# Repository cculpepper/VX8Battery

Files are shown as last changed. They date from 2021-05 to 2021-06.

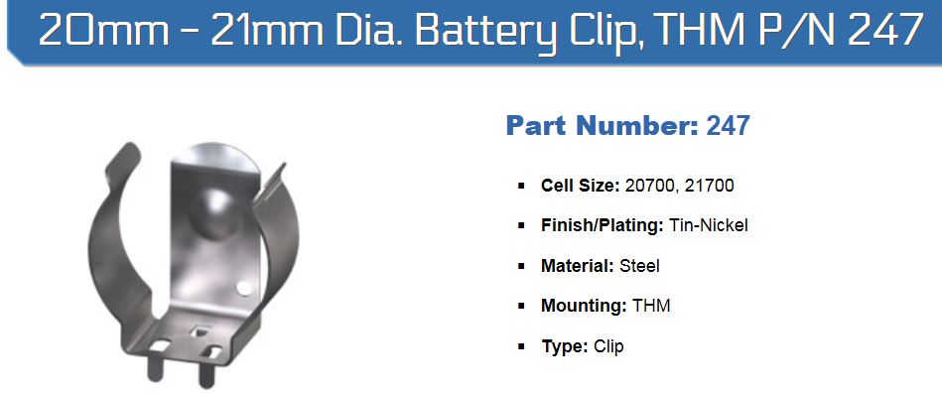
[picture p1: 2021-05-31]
backPlate/keystone-electronics-21700-20700-single-cell-clip-pth-1.snapshot.1/Keystone-PN247 specification.JPG

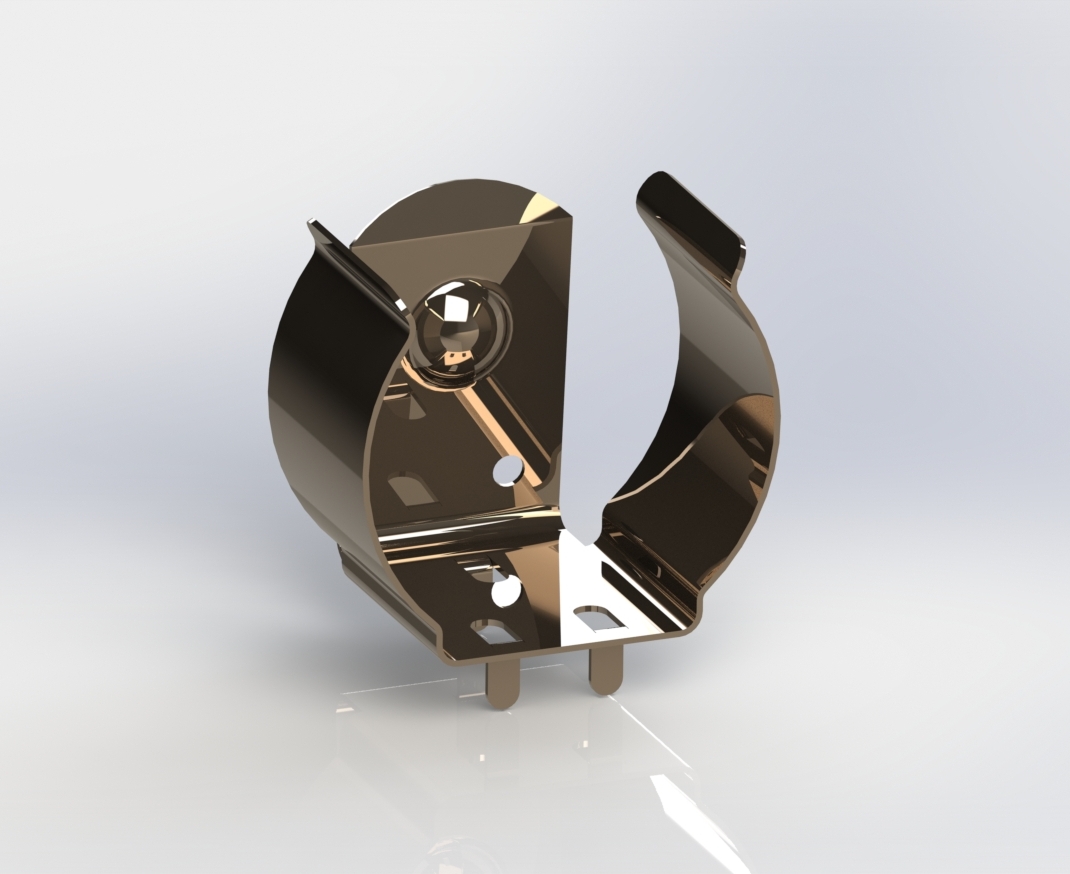
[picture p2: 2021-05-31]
backPlate/keystone-electronics-21700-20700-single-cell-clip-pth-1.snapshot.1/keystone-PN247 iso rendering.JPG

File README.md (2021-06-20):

This is a printed and PCB'ed battery for the VX8DR. 

I've been using it for approx 2 days now, and it seems to work great. 

I printed the case, backPlate/VX8PrintedCase-WithLightPipes.stl in PLA, 0.15mm. The 0.15 or smaller seems to be important for the clips, so you have more walls. It features two heat-serts for M3 screws for the beltclip. You may want to trim with a file the clips and the passive end clips, but I did not need to. The light pipes were made of 1.75mm clear PETG, and I had to drill them out to 2mm in post. The USB-C hole fits all of my cables, and is probably a bit too big so you'll have to fish around in there to plug it in. 

I had the PCB made up in 0.8mm from JLCPCB, seems to work great, but does bend a bit. The SMT nuts are from adafruit, https://www.adafruit.com/product/4207 . These work great. The interactive bom is in the circuit folder, and should have relevant manufacturer PNs from Digikey, except for the jellybean parts. The chip will charge at 1.2A from the 5V line, and will /eventually/ balance unbalanced cells. There is NO PROTECTION between the cells and the radio interface, so you should use protected cells...

After soldering, you'll need to grind or file the battery clips, SMT nuts, and thermistor to not protrude. IT IS IMPORTANT TO INSULATE THE BACK OF THE PCB. I used 2 layers of kapton. Don't screw this up! 
Also you'll need to trim the "bottom" of the attached PCB, you'll see that it doesn't fit into the 3d printed case. When I up the PCB version, I'll fix that. 

For assembly, I found the easiest thing (after testing the cells fit) is to put the cells into the case in the right orientation, then put the PCB with the battery clips in, "catching" the batteries. Then you can put in the M3 screws into the SMT nuts.

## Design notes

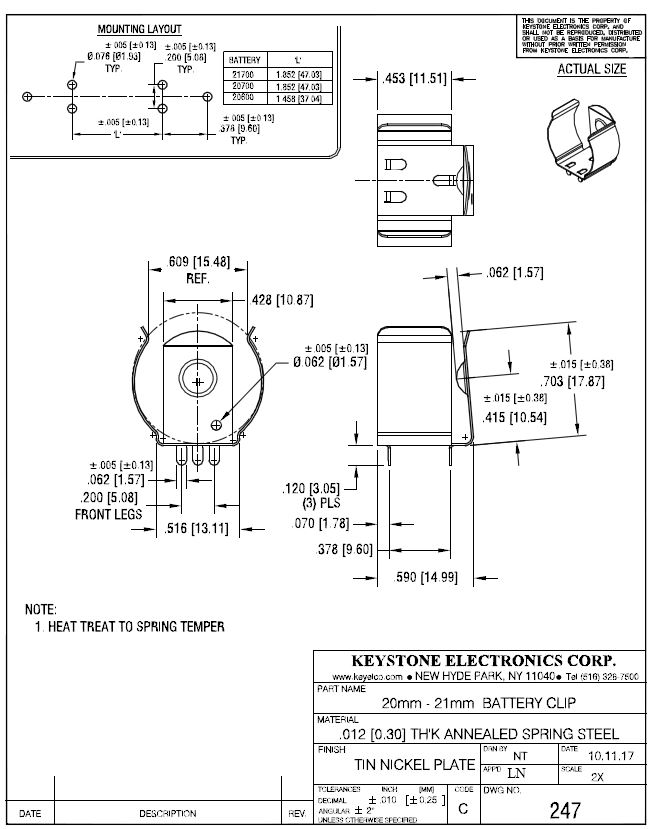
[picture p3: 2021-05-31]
backPlate/keystone-electronics-21700-20700-single-cell-clip-pth-1.snapshot.1/Keystone-PN247 mechanical.JPG

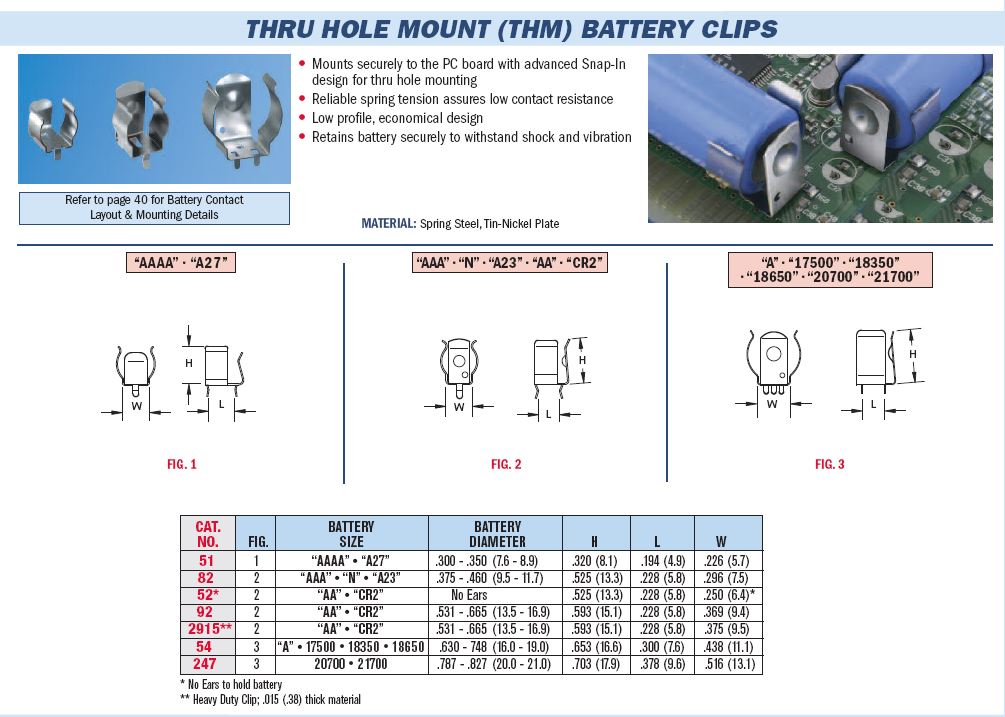
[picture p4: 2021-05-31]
backPlate/keystone-electronics-21700-20700-single-cell-clip-pth-1.snapshot.1/Keystone-PN247 catalog.JPG

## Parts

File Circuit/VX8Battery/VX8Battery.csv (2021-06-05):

Source: | /home/chris/Code/VX8Battery/Circuit/VX8Battery/VX8Battery.kicad_sch
Date: | Fri 04 Jun 2021 10:37:11 PM EDT
Tool: | Eeschema (5.99.0-10712-g3100cd3599)
Generator: | /usr/share/kicad/plugins/bom_csv_grouped_by_value.py
Component Count: | 28
Individual Components:
Item | Qty | Reference(s) | Value | LibPart | Footprint | Datasheet | Manufacturer PN
 |  | BT1 | Battery_Cell | Device:Battery_Cell | VX8Battery:21700Battery | ~
 |  | BT2 | Battery_Cell | Device:Battery_Cell | VX8Battery:21700Battery | ~
 |  | C1 | 10uF | Device:C | Capacitor_SMD:C_1210_3225Metric | ~
 |  | C2 | 100n | Device:C | Capacitor_SMD:C_0603_1608Metric | ~
 |  | C3 | 4.7uF | Device:C | Capacitor_SMD:C_1206_3216Metric | ~
 |  | C4 | 1uF | Device:C | Capacitor_SMD:C_0805_2012Metric | ~
 |  | C5 | 22u | Device:C | Capacitor_SMD:C_1210_3225Metric | ~ | GRM21BR61E226ME44K
 |  | D1 | LED | Device:LED | LED_SMD:LED_0603_1608Metric | ~
 |  | D2 | LED | Device:LED | LED_SMD:LED_0603_1608Metric | ~
 |  | H1 | MountingHole_Pad | Mechanical:MountingHole_Pad | VX8Battery:AdafruitSMTStandoff | ~
 |  | H2 | MountingHole_Pad | Mechanical:MountingHole_Pad | VX8Battery:AdafruitSMTStandoff | ~
 |  | H3 | MountingHole_Pad | Mechanical:MountingHole_Pad | VX8Battery:AdafruitSMTStandoff | ~
 |  | J1 | USBC-Molex-2171780001 | VX8Battery:USBC-Molex-2171780001 | VX8Battery:Molex-2171780001
 |  | J2 | VX8BattPins | Connector:Conn_01x03_Female | VX8Battery:VX8BatteryPins | ~
 |  | L1 | 1.5uH | Device:L | Inductor_SMD:L_Taiyo-Yuden_NR-50xx_HandSoldering | ~ | TYS50402R2N-10
 |  | R1 | R | Device:R | Resistor_SMD:R_0603_1608Metric | ~
 |  | R2 | R | Device:R | Resistor_SMD:R_0603_1608Metric | ~
 |  | R3 | 28.7K | Device:R | Resistor_SMD:R_0603_1608Metric | ~
 |  | R4 | 10K | Device:R | Resistor_SMD:R_0603_1608Metric | ~
 |  | R5 | R | Device:R | Resistor_SMD:R_0603_1608Metric | ~
 |  | R6 | R | Device:R | Resistor_SMD:R_0603_1608Metric | ~
 |  | R7 | 20K | Device:R | Resistor_SMD:R_0603_1608Metric | ~
 |  | R8 | 17K | Device:R | Resistor_SMD:R_0603_1608Metric | ~
 |  | R9 | 100 | Device:R | Resistor_SMD:R_0603_1608Metric | ~
 |  | R10 | 12.62K | Device:R | Resistor_SMD:R_0603_1608Metric | ~
 |  | R11 | 3.63K | Device:R | Resistor_SMD:R_0603_1608Metric | ~
 |  | TH1 | Thermistor_NTC | Device:Thermistor_NTC | Resistor_THT:R_Axial_DIN0204_L3.6mm_D1.6mm_P2.54mm_Vertical | ~ | NTCLE101E3C90173
 |  | U1 | MP2672A | VX8Battery:MP2672A | VX8Battery:MP2672A
Collated Components:
Item | Qty | Reference(s) | Value | LibPart | Footprint | Datasheet | Manufacturer PN
1 | 2 | BT1, BT2 | Battery_Cell | Device:Battery_Cell | VX8Battery:21700Battery | ~
2 | 1 | C1 | 10uF | Device:C | Capacitor_SMD:C_1210_3225Metric | ~
3 | 1 | C2 | 100n | Device:C | Capacitor_SMD:C_0603_1608Metric | ~
4 | 1 | C3 | 4.7uF | Device:C | Capacitor_SMD:C_1206_3216Metric | ~
5 | 1 | C4 | 1uF | Device:C | Capacitor_SMD:C_0805_2012Metric | ~
6 | 1 | C5 | 22u | Device:C | Capacitor_SMD:C_1210_3225Metric | ~ | GRM21BR61E226ME44K
7 | 2 | D1, D2 | LED | Device:LED | LED_SMD:LED_0603_1608Metric | ~
8 | 3 | H1, H2, H3 | MountingHole_Pad | Mechanical:MountingHole_Pad | VX8Battery:AdafruitSMTStandoff | ~
9 | 1 | J1 | USBC-Molex-2171780001 | VX8Battery:USBC-Molex-2171780001 | VX8Battery:Molex-2171780001
10 | 1 | J2 | VX8BattPins | Connector:Conn_01x03_Female | VX8Battery:VX8BatteryPins | ~
11 | 1 | L1 | 1.5uH | Device:L | Inductor_SMD:L_Taiyo-Yuden_NR-50xx_HandSoldering | ~ | TYS50402R2N-10
12 | 4 | R1, R2, R5, R6 | R | Device:R | Resistor_SMD:R_0603_1608Metric | ~
13 | 1 | R3 | 28.7K | Device:R | Resistor_SMD:R_0603_1608Metric | ~
14 | 1 | R4 | 10K | Device:R | Resistor_SMD:R_0603_1608Metric | ~
15 | 1 | R7 | 20K | Device:R | Resistor_SMD:R_0603_1608Metric | ~
16 | 1 | R8 | 17K | Device:R | Resistor_SMD:R_0603_1608Metric | ~
17 | 1 | R9 | 100 | Device:R | Resistor_SMD:R_0603_1608Metric | ~
18 | 1 | R10 | 12.62K | Device:R | Resistor_SMD:R_0603_1608Metric | ~
19 | 1 | R11 | 3.63K | Device:R | Resistor_SMD:R_0603_1608Metric | ~
20 | 1 | TH1 | Thermistor_NTC | Device:Thermistor_NTC | Resistor_THT:R_Axial_DIN0204_L3.6mm_D1.6mm_P2.54mm_Vertical | ~ | NTCLE101E3C90173
21 | 1 | U1 | MP2672A | VX8Battery:MP2672A | VX8Battery:MP2672A

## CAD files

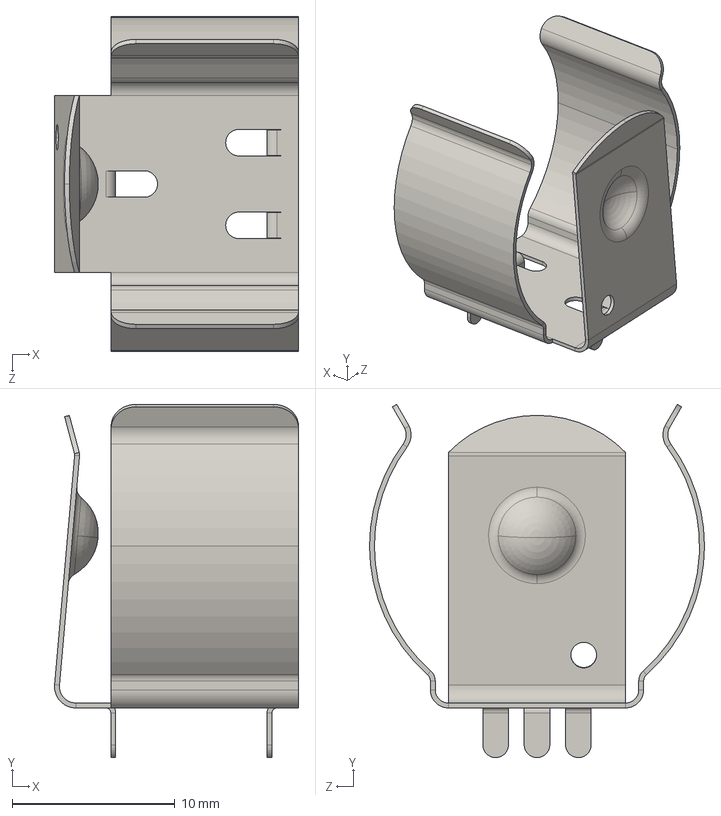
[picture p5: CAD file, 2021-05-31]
backPlate/keystone-electronics-21700-20700-single-cell-clip-pth-1.snapshot.1/keystone-PN247.STEP
15.0 x 21.7 x 20.6 mm

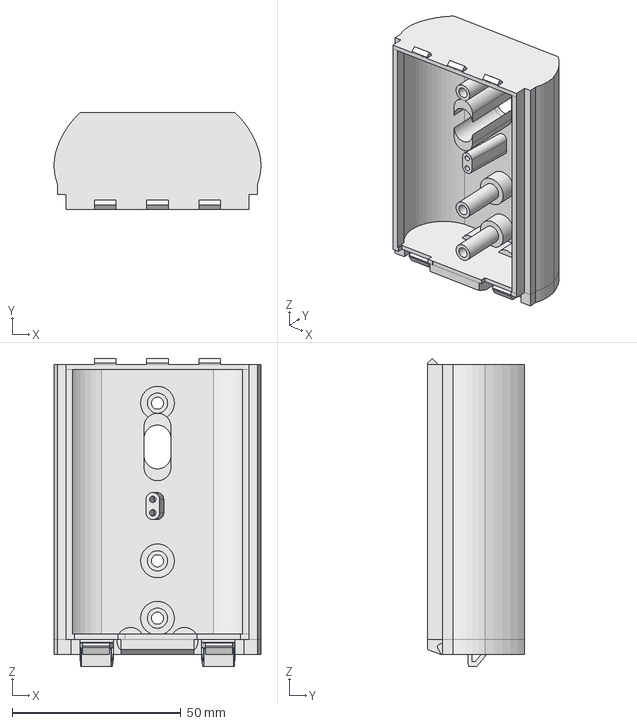
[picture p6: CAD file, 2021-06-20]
backPlate/VX8PrintedCase.FCStd
61.4 x 28.8 x 91.3 mm

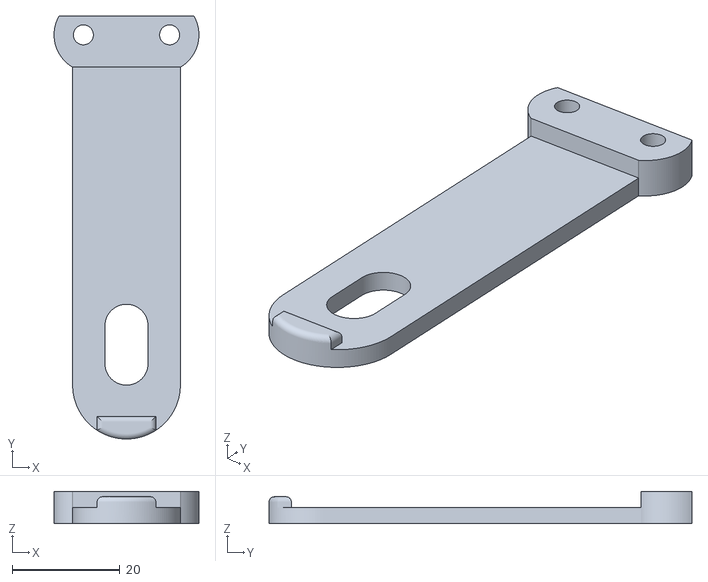
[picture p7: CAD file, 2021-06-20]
backPlate/VX8PrintedCaseBeltClip-BeltClipFillet.stl
26.9 x 78.5 x 6.00

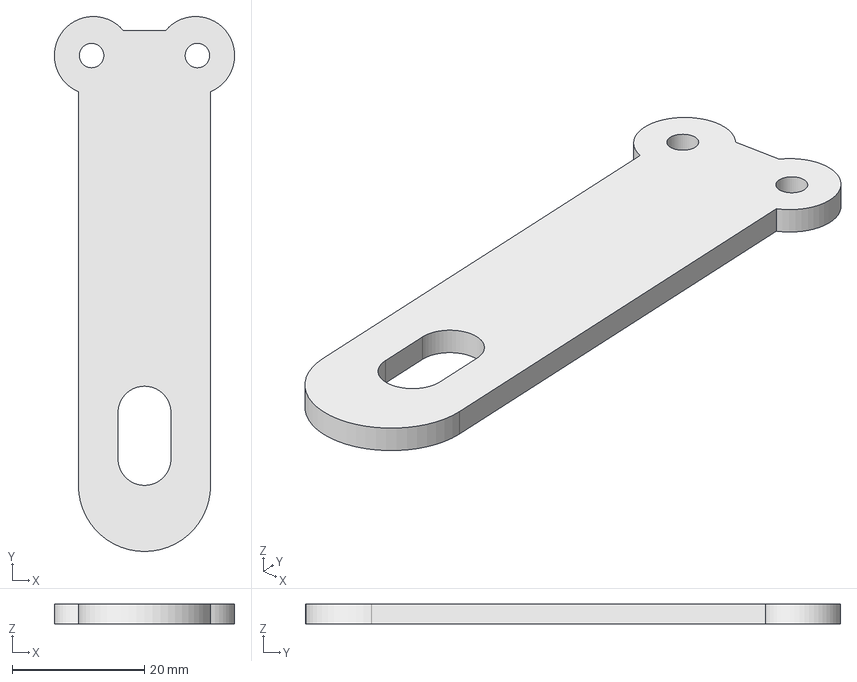
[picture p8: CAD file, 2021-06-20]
backPlate/VX8PrintedCaseBeltClip.FCStd
27.3 x 80.9 x 3.00 mm

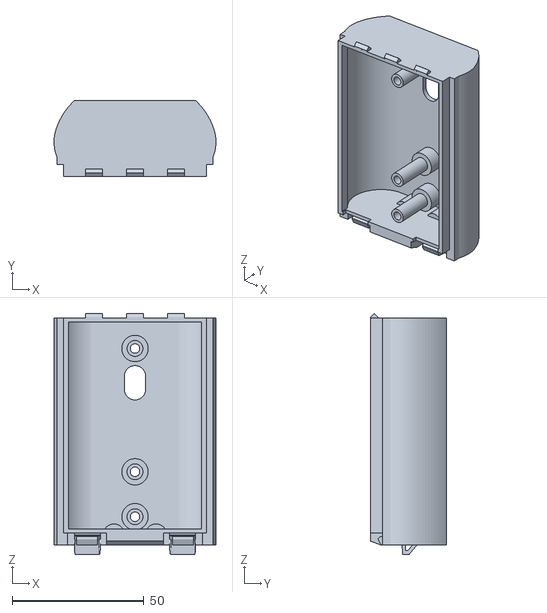
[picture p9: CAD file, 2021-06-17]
backPlate/VX8PrintedCase-WithOUTLightPipes.stl
61.4 x 28.8 x 91.3

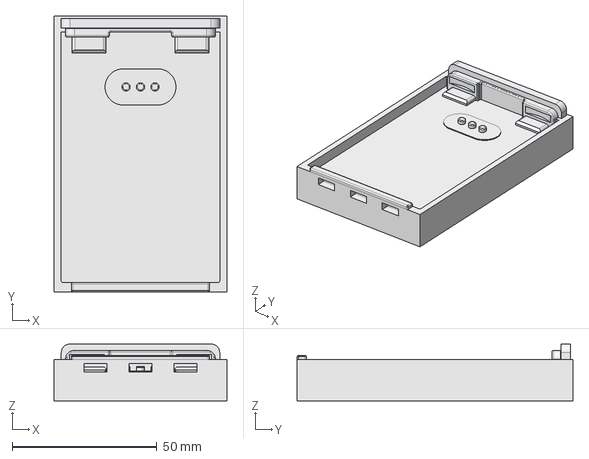
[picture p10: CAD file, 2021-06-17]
backPlate/VX8Model.FCStd
59.8 x 95.2 x 19.7 mm

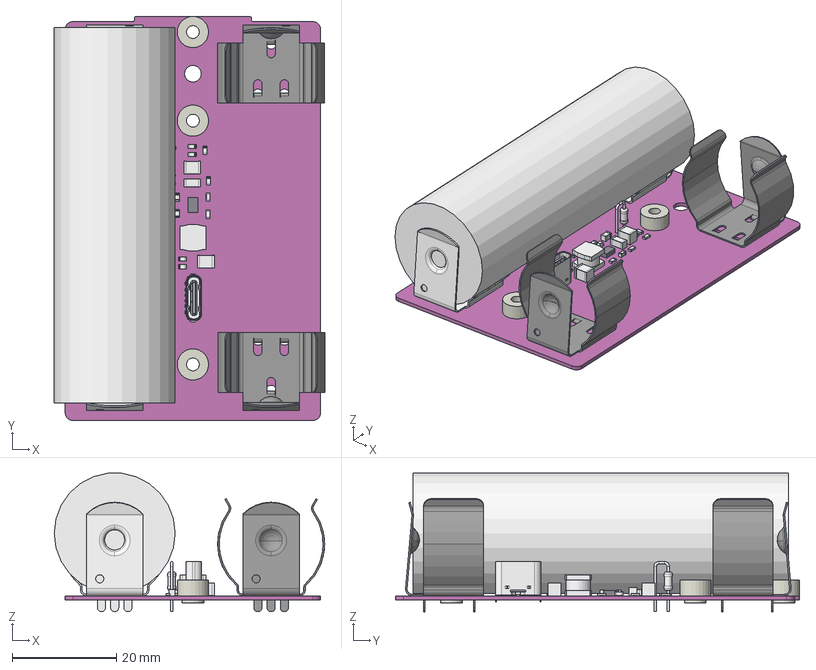
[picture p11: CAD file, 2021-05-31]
backPlate/VX8BatteryPCB.FCStd
51.9 x 77.5 x 26.6 mm
TH1_R_Axial_DIN0204_L36mm_D16mm_P254mm_Vertical_99c942fc799d
R1_R_0603_1608Metric_e04d69ce8836 x 11
U1_MP2672A_023df3fe17b2
H1_Mounting_Wuerth_WA_SMSI_M3_H3mm_9774030360_f84d812b874e x 3
J1_MolexVerticalSMDUSBC_3ee5f35280ab
C5_C_1210_3225Metric_d43db624757c x 2
C2_C_0603_1608Metric_7b14ea18a6a0
C4_C_0805_2012Metric_7cbe0b741b72
21700BatteryHolder-WithBattery
21700BatteryHolder-WithBattery001
21700BatteryHolder-WithBattery002
D2_LED_0603_1608Metric_f960d8dfa779 x 2
21700BatteryHolder-NoBattery
21700BatteryHolder-NoBattery001
inductor
inductor001
inductor002
C3_C_1206_3216Metric_fab75bc0fda4
Pcb_a240

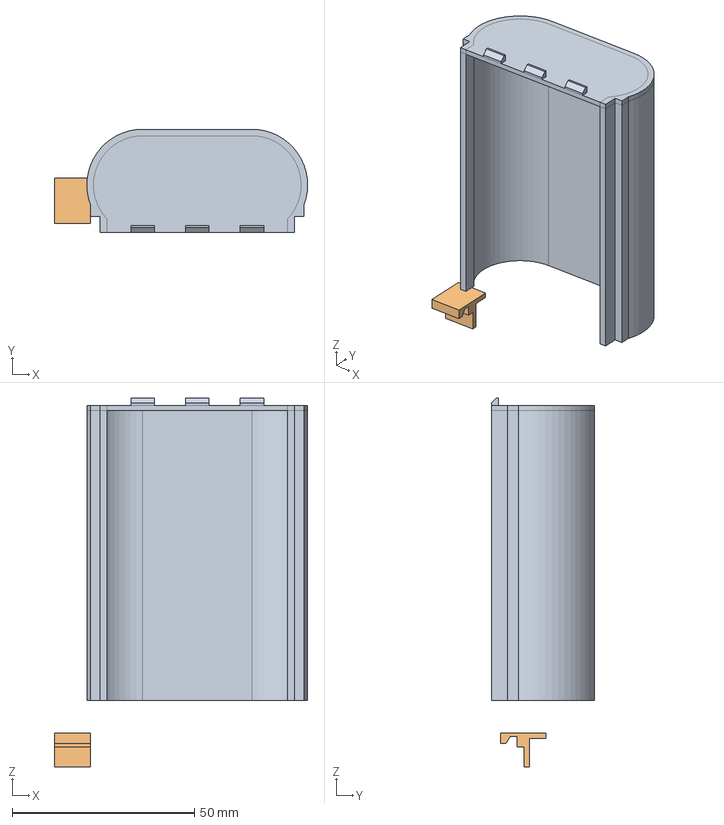
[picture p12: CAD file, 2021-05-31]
backPlate/BatteryClip.FCStd
69.6 x 28.4 x 101.3 mm
BaseFeature

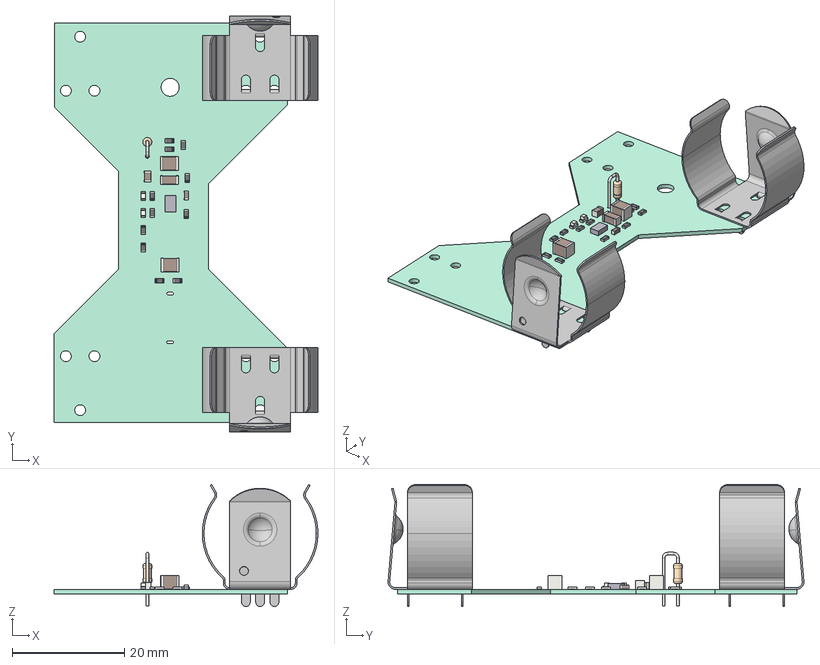
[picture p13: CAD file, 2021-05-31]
backPlate/VX8BatteryPCB-VX8Battery.step
46.9 x 74.0 x 21.7 mm
Pcb_a240
TH1_R_Axial_DIN0204_L36mm_D16mm_P254mm_Vertical_99c942fc799d
R1_R_0603_1608Metric_e04d69ce8836 x 11
U1_MP2672A_023df3fe17b2
C5_C_1210_3225Metric_d43db624757c x 2
C2_C_0603_1608Metric_7b14ea18a6a0
C4_C_0805_2012Metric_7cbe0b741b72
D2_LED_0603_1608Metric_f960d8dfa779 x 2
21700BatteryModel-NoBattery
21700BatteryModel-NoBattery001
C3_C_1206_3216Metric_fab75bc0fda4

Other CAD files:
backPlate/VX8BatteryAssembly.FCStd
backPlate/VX8PrintedCase-WithLightPipes.stl

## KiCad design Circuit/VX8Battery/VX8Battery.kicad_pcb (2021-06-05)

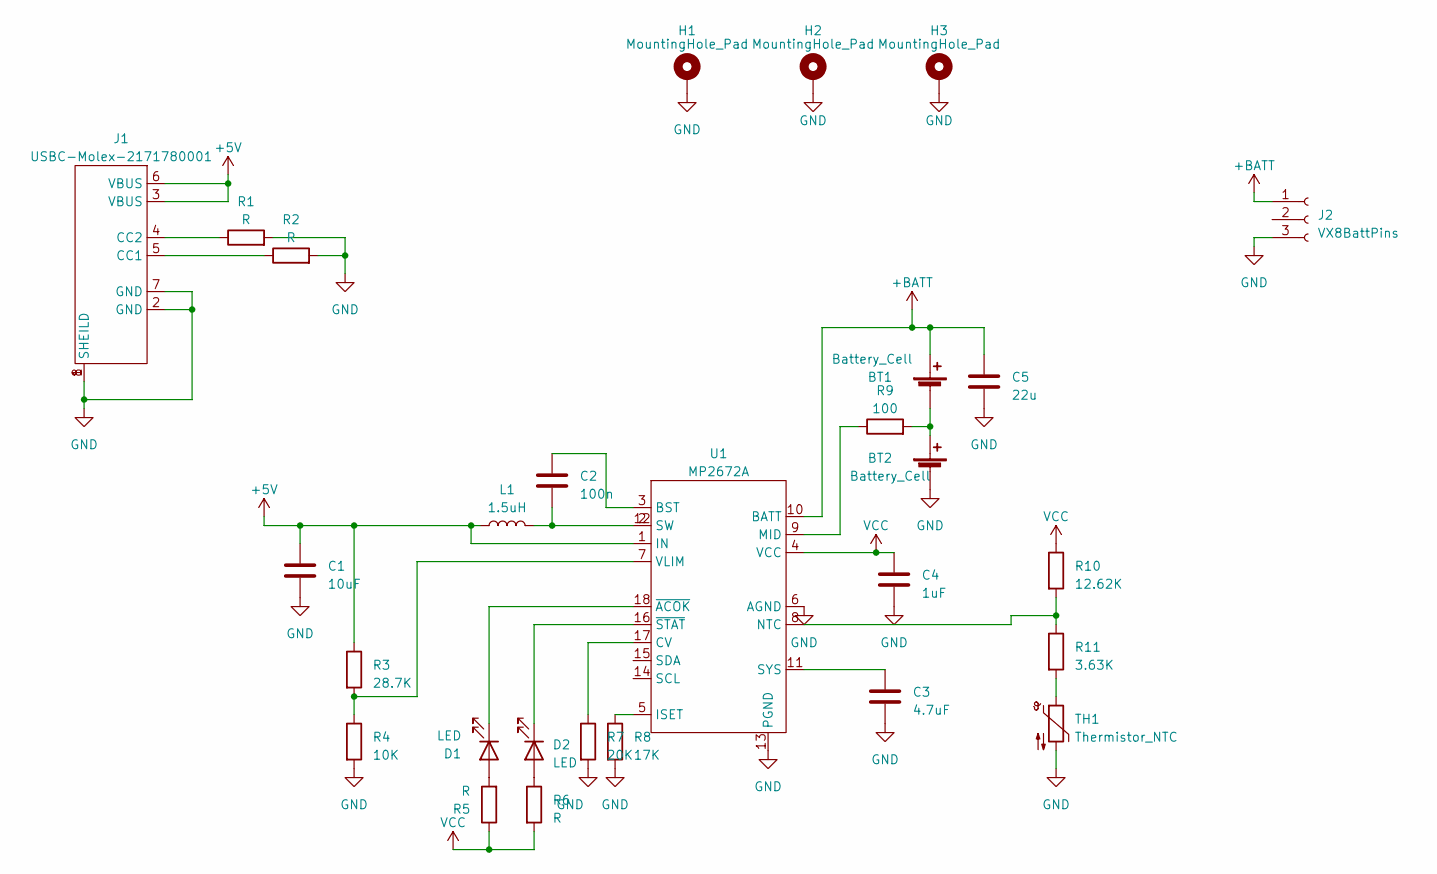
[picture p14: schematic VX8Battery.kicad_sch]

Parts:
BT1, BT2: Battery_Cell; 21700Battery
C1: 10uF; C_1210_3225Metric
C2: 100n; C_0603_1608Metric
C3: 4.7uF; C_1206_3216Metric
C4: 1uF; C_0805_2012Metric
C5: 22u; C_1210_3225Metric; Manufacturer PN GRM21BR61E226ME44K
D1, D2: LED; LED_0603_1608Metric
H1, H2, H3: MountingHole_Pad; AdafruitSMTStandoff
J1: USBC-Molex-2171780001; Molex-2171780001
J2: VX8BattPins; VX8BatteryPins
L1: 1.5uH; L_Taiyo-Yuden_NR-50xx_HandSoldering; Manufacturer PN TYS50402R2N-10
R1, R2, R5, R6: R; R_0603_1608Metric
R3: 28.7K; R_0603_1608Metric
R4: 10K; R_0603_1608Metric
R7: 20K; R_0603_1608Metric
R8: 17K; R_0603_1608Metric
R9: 100; R_0603_1608Metric
R10: 12.62K; R_0603_1608Metric
R11: 3.63K; R_0603_1608Metric
TH1: Thermistor_NTC; R_Axial_DIN0204_L3.6mm_D1.6mm_P2.54mm_Vertical; Manufacturer PN NTCLE101E3C90173
U1: MP2672A

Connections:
+5V: C1.1, J1.3 (VBUS), J1.6 (VBUS), L1.1, R3.1, U1.1 (IN)
+BATT: BT1.1 (+), C5.1, J2.1, U1.10 (BATT)
GND: BT2.2 (-), C1.2, C3.2, C4.2, C5.2, H1.1, H2.1, H3.1, J1.1 (SHEILD), J1.2 (GND), J1.7 (GND), J1.8 (SHEILD), J2.3, R1.2, R2.2, R4.2, R7.2, R8.2, TH1.2, U1.6 (AGND), U1.13 (PGND)
unnamed: BT1.2 (-), BT2.1 (+), R9.2
unnamed: C2.1, L1.2, U1.2 (SW), U1.12 (SW)
unnamed: C2.2, U1.3 (BST)
unnamed: C3.1, U1.11 (SYS)
unnamed: D1.2 (A), R5.2
unnamed: D2.2 (A), R6.1
unnamed: J1.4 (CC2), R1.1
unnamed: J1.5 (CC1), R2.1
unnamed: R3.2, R4.1, U1.7 (VLIM)
unnamed: R7.1, U1.17 (CV)
unnamed: R8.1, U1.5 (ISET)
unnamed: R9.1, U1.9 (MID)
unnamed: R10.2, R11.1, U1.8 (NTC)
unnamed: R11.2, TH1.1
unnamed: D2.1 (K), U1.16 (~STAT)
unnamed: D1.1 (K), U1.18 (~ACOK)
VCC: C4.1, R5.1, R6.2, R10.1, U1.4 (VCC)

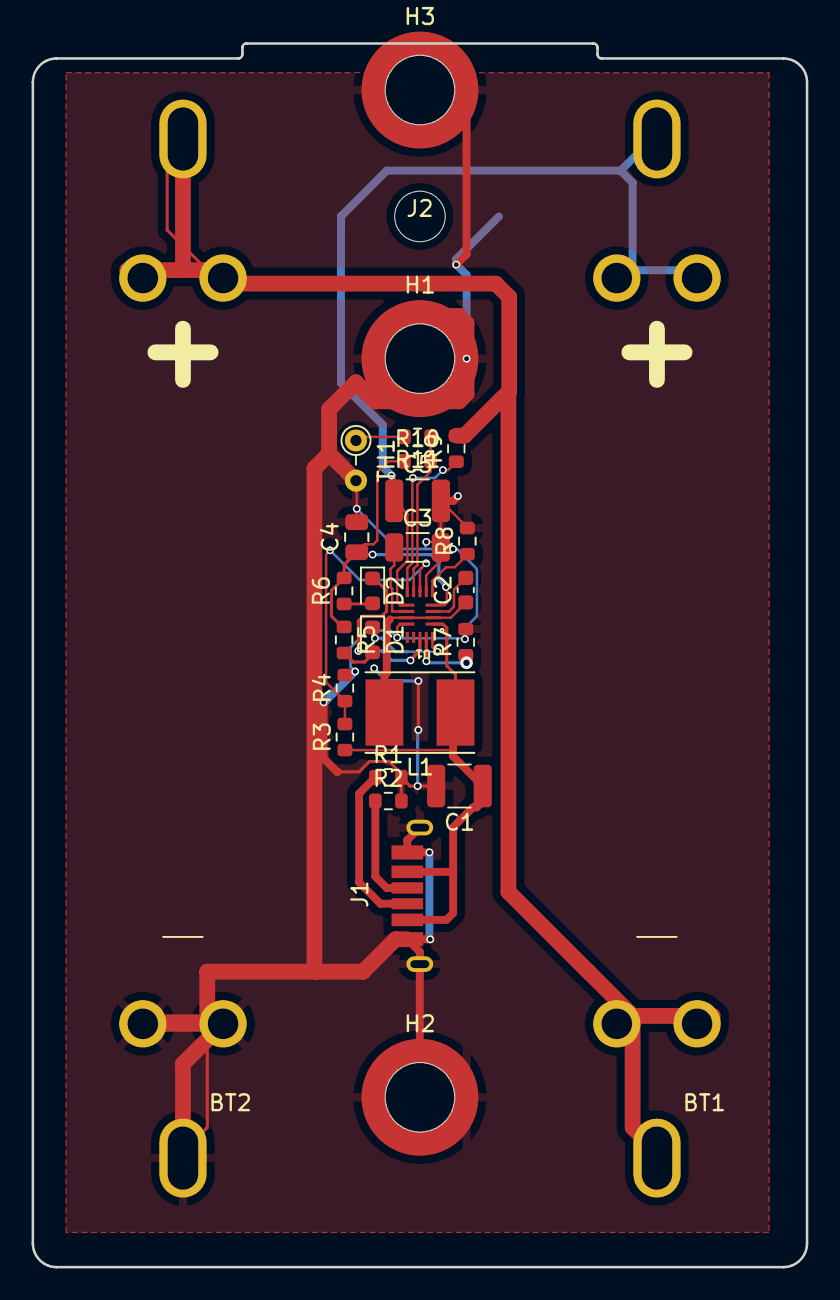
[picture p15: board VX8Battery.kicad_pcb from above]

Board: 2 copper layers, 49.0 x 77.4 mm, 28 parts (0 on the bottom side), 20 nets.

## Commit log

2021-05-31 Fixed up the battery case, and I wanted to commit before I eff it up again
    [BatteryClip.FCStd, VX8Battery.kicad_pcb, VX8Battery.kicad_sch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]
2021-06-01 Should be the right clearances, but am making one change which might f things up again...
    [VX8BatteryAssembly.FCStd, VX8PrintedCase.FCStd, testJig.stl]
2021-06-01 I think I fixed the printed case... I think something was corrupted. Hopefully I have no changes to make....
    [VX8BatteryAssembly.FCStd, VX8PrintedCase.FCStd]
2021-06-01 Modified the VX8 clips. Seems to be very delicate, bet edits can be made
    [VX8PrintedCase.FCStd]
2021-06-01 More printed case updates, changing something earlier in the tree keeps screwing up later things, but that seems not bad to fix.
    [VX8BatteryAssembly.FCStd, VX8PrintedCase.FCStd, testJig.stl]
2021-06-01 More clip adjustments
    [VX8PrintedCase.FCStd]
2021-06-05 Mostly circuit board updates. Still need to fix the dependency chart for the case
    [VX8Battery-B_Cu.gbr, VX8Battery-B_Mask.gbr, VX8Battery-B_Paste.gbr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]
2021-06-17 Should be the finished version, at least finished enough for prod
    [VX8BatteryAssembly.FCStd, VX8Model.FCStd, VX8PrintedCase.FCStd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]
2021-06-17 Added stl, removed backups
    [VX8Battery.kicad_sch, VX8BatteryAssembly.FCStd, VX8PrintedCase-WithLightPipes.stl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]
2021-06-19 Added BOM
2021-06-20 Added a belt clip
    [VX8BatteryAssembly.FCStd, VX8PrintedCase.FCStd, VX8PrintedCaseBeltClip-BeltClipFillet.stl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]
2021-06-20 Added note about trimming PCB
